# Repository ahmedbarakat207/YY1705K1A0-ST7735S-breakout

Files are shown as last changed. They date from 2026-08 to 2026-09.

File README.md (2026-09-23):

# YY1705K1A0 ST7735S 1-Layer Breakout & Driver Library






An open-source, **1-layer single-sided PCB breakout board** and **high-performance C++ driver** for the **YY1705K1A0** 1.8-inch TFT LCD SPI display (ST7735S controller, 128×160 RGB).

---

## Features

- **100% Single-Sided (1-Layer F.Cu)**: Designed specifically for home etching (toner transfer / photoresist). Zero jumpers or bottom vias required.
- **Through-Hole Passives (no SMD soldering)**: R1, R2, R3, C1, C2 are all standard through-hole parts — solder them with any basic iron. The only SMD part is the J2 FPC ZIF connector (required by the display flex cable).
- **Zero DRC Violations**: Optimized trace widths (0.35 mm signals, 0.60 mm power/GND) with 0.30 mm minimum clearances.
- **Clean Silkscreen**: Professional component labeling with open routing corridors.
- **Header-Only C++ Driver (`YY1705K1A0.h`)**:
  - Hardware SPI (fast DMA-capable) and Software bit-bang SPI constructors.
  - Complete 23-color RGB565 palette + `TFT_COLOR(r,g,b)` macro.
  - Fast graphic primitives (pixels, lines, rects, rounded rects, circles, triangles).
  - Built-in 5×7 ASCII font with scaling and Arduino `Print` interface (`print`/`println`).
  - Pre-built UI widgets (`drawProgressBar`).
  - Native support for display sleep, vertical scrolling, rotation (0°–270°), and partial mode.

---

## Hardware Overview

| Parameter | Specification |
|---|---|
| **Display Model** | YY1705K1A0 (1.8" TFT, 128×160) |
| **Driver IC** | Sitronix ST7735S |
| **Board Dimensions** | 34.0 mm × 53.0 mm |
| **Layers** | 1-Layer (Top Copper `F.Cu` Only) |
| **Interface** | 4-Wire SPI (3.3V Logic) |
| **Connectors** | `J1`: 7-Pin 2.54mm Header, `J2`: 12-Pin 0.5mm FPC |

---

## Pinout & Wiring

> **IMPORTANT**: This board and display operate strictly on **3.3V logic**. When interfacing with 5V microcontrollers (e.g. Arduino Uno / Mega), use a logic level shifter.

| J1 Pin | Label | Function | FPC Pin (J2) | MCU Connection (e.g., ESP32 / Arduino) |
|:---:|:---:|---|:---:|---|
| **1** | `+3V3` | +3.3V Power Supply | Pin 10 (`VDD`) | 3.3V Power Out |
| **2** | `GND` | Ground | Pins 2, 4, 11 | GND |
| **3** | `RST` | Reset (Active LOW) | Pin 5 (`RES`) | GPIO (e.g., D8) |
| **4** | `DC` | Data / Command Select | Pin 6 (`A0`) | GPIO (e.g., D9) |
| **5** | `MOSI` | SPI Data (SDA) | Pin 7 (`SDA`) | SPI MOSI (e.g., D11 / GPIO 23) |
| **6** | `SCK` | SPI Clock (SCL) | Pin 8 (`SCL`) | SPI SCK (e.g., D13 / GPIO 18) |
| **7** | `CS` | Chip Select (Active LOW) | Pin 9 (`CS`) | GPIO (e.g., D10 / GPIO 5) |

---

## Bill of Materials (BOM)

| Designator | Description | Package / Footprint | Quantity |
|---|---|---|:---:|
| **J1** | 7-Pin 2.54mm Header Male/Female | 1×07 Pin Header (0.1") THT | 1 |
| **J2** | 12-Pin 0.5mm Pitch Bottom-Contact FPC Connector | SMD 12-Pin 0.5mm **(only SMD part)** | 1 |
| **R1** | 22 Ω Backlight Current Limiter | Axial 1/4W THT, 7.62mm pitch (lying flat) | 1 |
| **R2, R3** | 10 kΩ Pull-up Resistors (`RESET`, `CS`) | Axial 1/4W THT, 5.08mm pitch (vertical mount) | 2 |
| **C1** | 10 µF 10V Ceramic/Electrolytic (Bulk Decoupling) | Disc/Radial THT, 5mm pitch | 1 |
| **C2** | 100 nF (0.1 µF) Ceramic Disc (HF Bypass) | Disc THT, 5mm pitch | 1 |

---

## Quick Start (Arduino / PlatformIO)

### Installation

1. Copy `YY1705K1A0.h` into your Arduino sketch folder or PlatformIO project `include/` directory.
2. In your sketch:

```cpp
#include <SPI.h>
#include "YY1705K1A0.h"

// Define pins
#define TFT_CS    10
#define TFT_DC    9
#define TFT_RST   8

// Hardware SPI instance (Fastest)
YY1705K1A0 tft(TFT_CS, TFT_DC, TFT_RST);

void setup() {
    // Initialize display with standard black-tab profile
    tft.begin(INITR_BLACKTAB);
    tft.fillScreen(TFT_BLACK);

    // Print text
    tft.setTextColor(TFT_WHITE, TFT_BLACK);
    tft.drawString(10, 20, "Hello World!", TFT_YELLOW, TFT_BLACK, 2);

    // Draw UI shapes
    tft.drawRoundRect(10, 60, 108, 30, 4, TFT_CYAN);
    tft.drawProgressBar(10, 100, 108, 14, 75, TFT_GREEN, TFT_DARKGREY, TFT_WHITE);
}

void loop() {
}
```

---

## DIY PCB Fabrication (Toner Transfer)

Print-ready vector PDF files scaled at 1:1 for DIY etching:

- **[YY1705K1A0_breakout_scaled_landscape.pdf](YY1705K1A0_breakout_scaled_landscape.pdf)**: 2 scaled boards per A4 page.
- **[YY1705K1A0_breakout_scaled_landscape_mirrored.pdf](YY1705K1A0_breakout_scaled_landscape_mirrored.pdf)**: Mirrored for direct iron-on toner transfer.

> **Printing Note**: Print with **Scale: 100% / Actual Size** enabled in your PDF viewer.

---

## Repository Structure

```
├── README.md                                          # Project documentation
├── LICENSE                                            # MIT Open-Source License
├── library.properties                                 # Arduino Library descriptor
├── library.json                                       # PlatformIO Library descriptor
├── YY1705K1A0.h                                       # Display driver header library
├── YY1705K1A0_breakout.kicad_pro                      # KiCad project file
├── YY1705K1A0_breakout.kicad_sch                      # KiCad schematic
├── YY1705K1A0_breakout.kicad_pcb                      # KiCad 1-layer PCB layout
├── BOM.csv                                            # Bill of Materials
├── display_connector_pinout.csv                       # FPC 12-pin reference sheet
├── WIRING_GUIDE.md                                    # Detailed wiring instructions
├── YY1705K1A0_breakout_scaled_landscape.pdf           # Printable A4 etching mask
├── YY1705K1A0_breakout_scaled_landscape_mirrored.pdf  # Mirrored etching mask
└── examples/
    └── GraphicTest/
        └── GraphicTest.ino                            # Complete demo sketch
```

---

## License

This project is open-source hardware and software licensed under the [MIT License](LICENSE).

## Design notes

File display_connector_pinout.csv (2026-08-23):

Pin | Signal | Function | Connection | Notes
1 | LEDA | Backlight anode | +3.3V rail | Through 22 ohm 1/4W SMD resistor in series
2 | LEDK | Backlight cathode | GND plane | Direct connection
3 | VDD | Logic power | +3.3V rail | Place 10uF and 0.1uF decoupling caps to GND at this pin
4 | VDDIO | IO logic power | Pin 3 (+3.3V) | Tie directly to VDD
5 | GND | Ground | GND plane | Direct connection
6 | RESET | Reset signal | GPIO4 | Optional 10k ohm pull-up to 3.3V
7 | DC / A0 | Data/command select | GPIO2 | Direct connection
8 | SDA / MOSI | SPI data | GPIO23 | Direct connection
9 | SCL / SCK | SPI clock | GPIO18 | Direct connection
10 | CS | Chip select | GPIO5 | Optional 10k ohm pull-up to 3.3V
11 | Shield / core GND | Shield ground | GND plane | Direct connection
12 | NC | Not connected | None | Leave pad isolated - do not route

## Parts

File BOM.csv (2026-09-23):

Reference | Value | Footprint | Qty | Description | Manufacturer | MPN | Mouser / LCSC PN | Notes
J2 | FPC_ZIF_12_0.5mm | Local:FPC_12_0.5mm | 1 | 12-pin 0.5mm pitch ZIF FPC connector top-contact (SMD — only SMD part on board) | Molex | 54548-1271 | 538-54548-1271 | Must match display flex cable pitch — verify with calipers.
J1 | ESP32_HDR_7 | PinHeader_1x07_P2.54mm | 1 | 1×7 2.54mm break-away male pin header (through-hole) | Any |  |  | Mating: 2.54mm female Dupont socket
R1 | 22R | Resistor_THT:R_Axial_DIN0207_L6.3mm_D2.5mm_P7.62mm_Horizontal | 1 | 22 ohm 1/4W axial THT resistor — LEDA backlight current limiter | Yageo | CFR-25JB-52-22R | 71-CFR-25JB-52-22R | Standard 1/4W carbon film or metal film axial (lying flat, 7.62mm lead pitch)
R2 | 10k | Resistor_THT:R_Axial_DIN0207_L6.3mm_D2.5mm_P5.08mm_Vertical | 1 | 10k ohm 1/4W axial THT — RESET pull-up resistor (vertical mount) | Yageo | CFR-25JB-52-10KL | 71-CFR-25JB-52-10KL | Vertical mount, 5.08mm lead pitch — stand one lead straight up
R3 | 10k | Resistor_THT:R_Axial_DIN0207_L6.3mm_D2.5mm_P5.08mm_Vertical | 1 | 10k ohm 1/4W axial THT — CS pull-up resistor (vertical mount) | Yageo | CFR-25JB-52-10KL | 71-CFR-25JB-52-10KL | Vertical mount, 5.08mm lead pitch — stand one lead straight up
C1 | 10uF | Capacitor_THT:C_Disc_D5.0mm_W2.5mm_P5.00mm | 1 | 10µF 10V+ ceramic disc or radial electrolytic capacitor — VDD bulk | Nichicon | UMT1A100MDD
C2 | 100nF | Capacitor_THT:C_Disc_D5.0mm_W2.5mm_P5.00mm | 1 | 100nF 50V+ ceramic disc capacitor (0.1µF) — VDD HF bypass | Kemet | C315C104M5U5TA | 80-C315C104M5U5TA

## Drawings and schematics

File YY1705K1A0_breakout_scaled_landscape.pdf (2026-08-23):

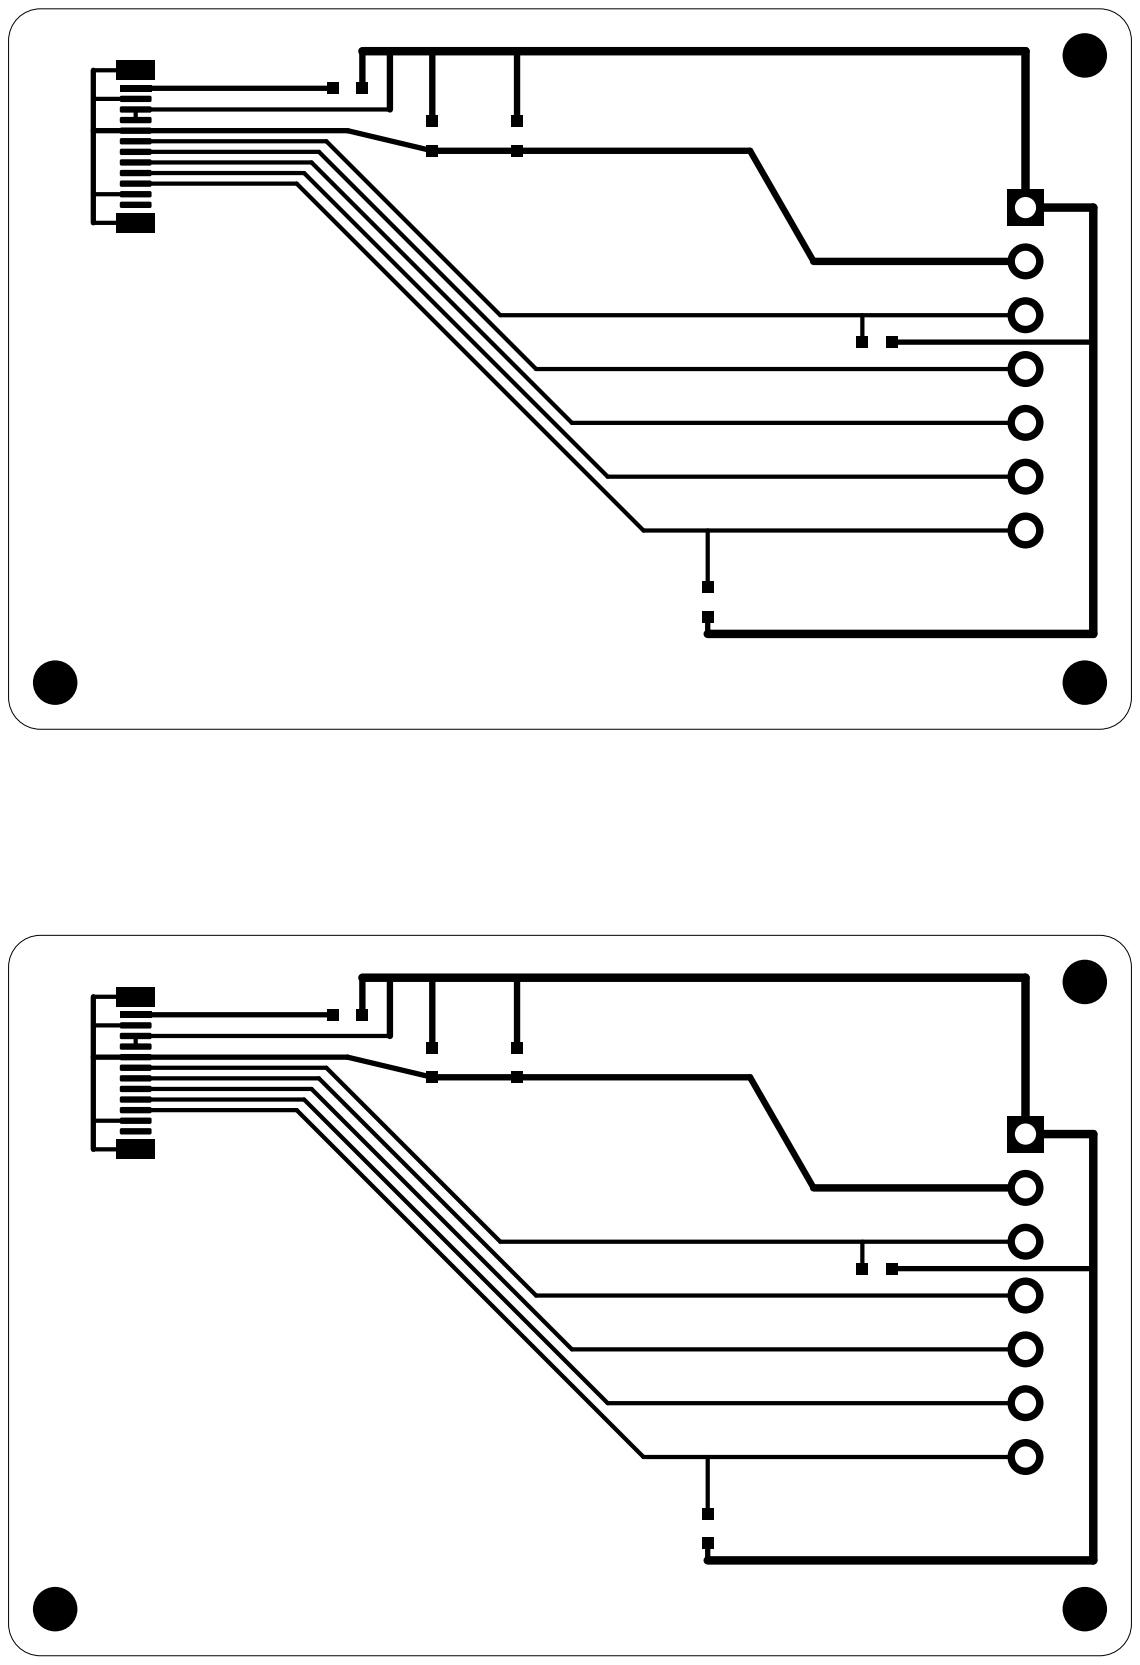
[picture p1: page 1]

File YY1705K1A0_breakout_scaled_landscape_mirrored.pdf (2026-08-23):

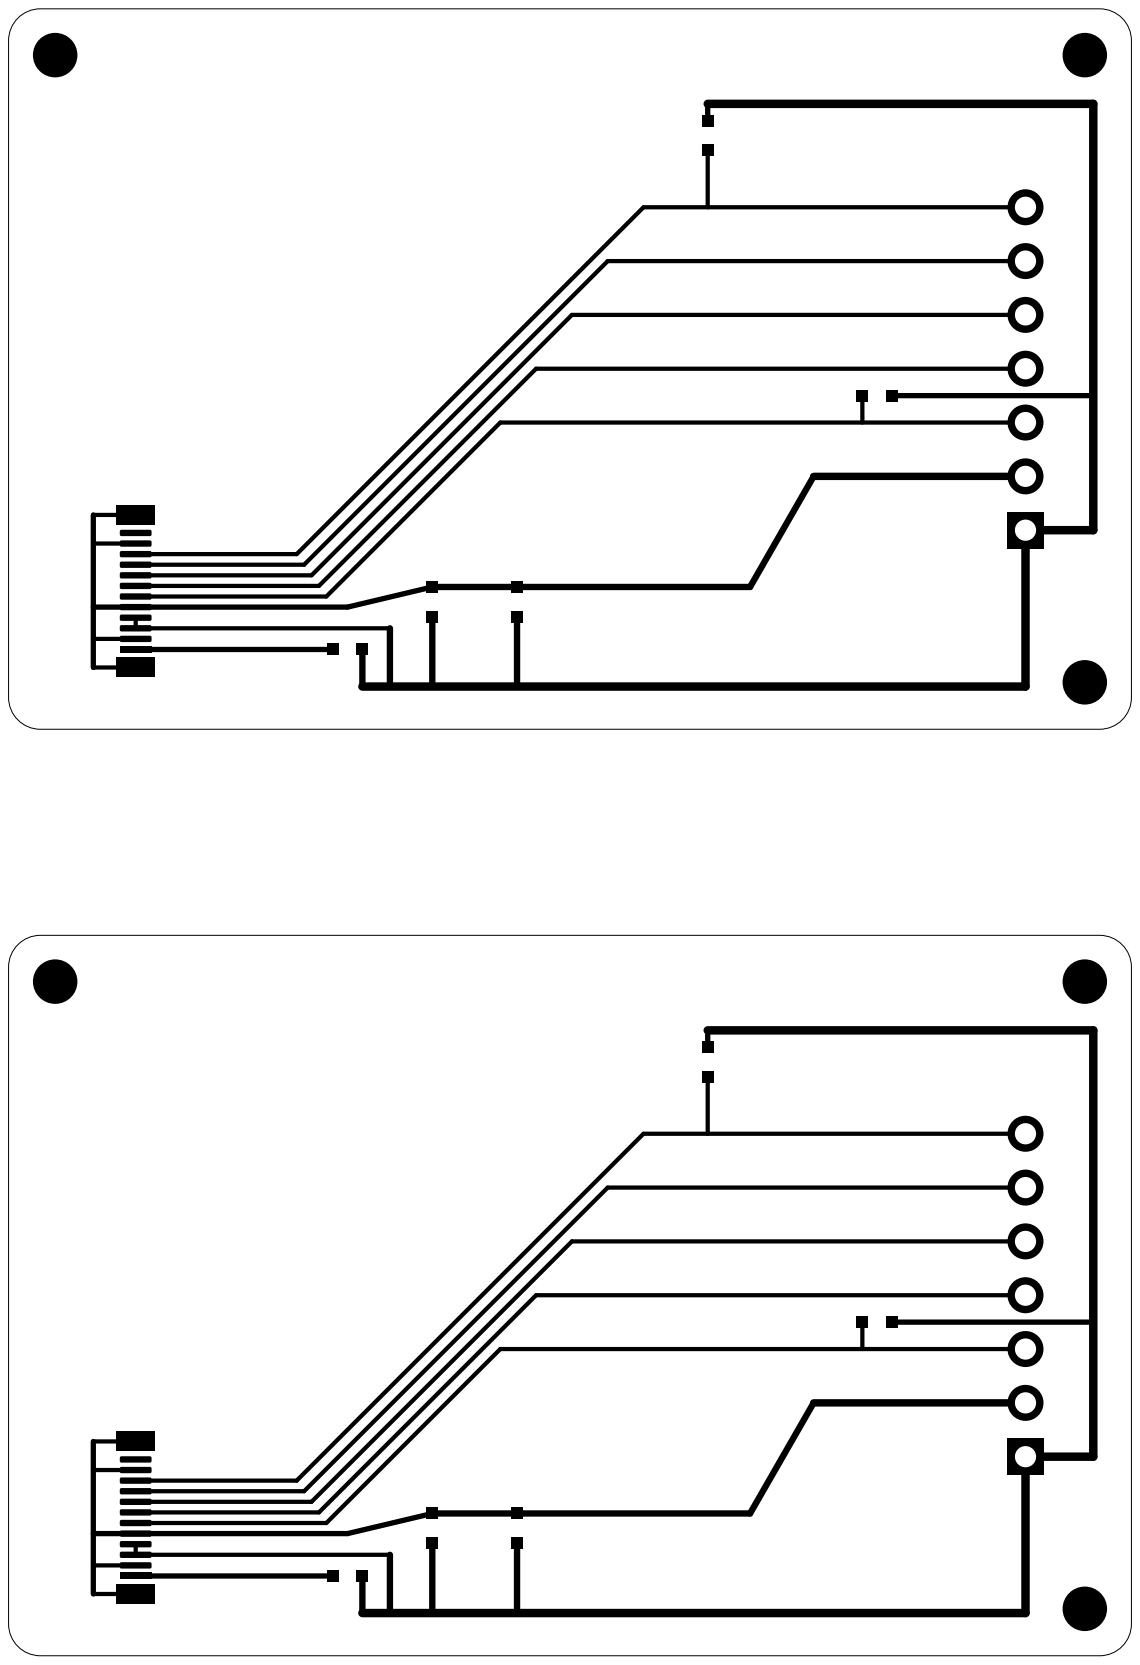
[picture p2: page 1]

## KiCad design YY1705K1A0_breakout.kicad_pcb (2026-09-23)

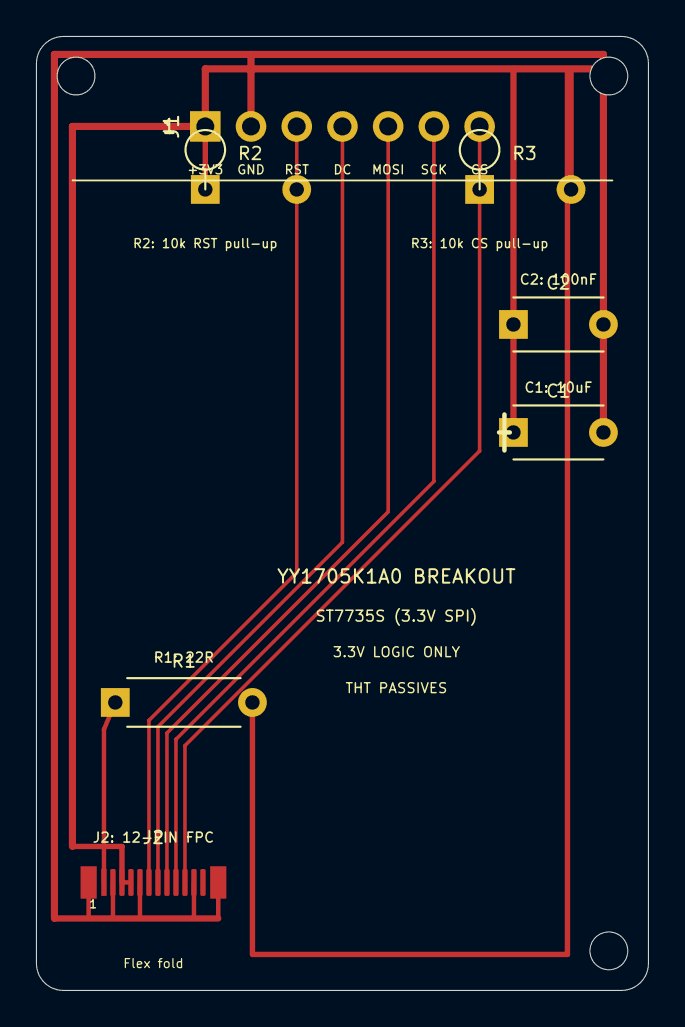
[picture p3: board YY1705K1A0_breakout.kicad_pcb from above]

Board: 2 copper layers, 34.0 x 53.0 mm, 10 parts (0 on the bottom side), 8 nets.

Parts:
C1: 10uF; C_Disc_D5.0mm_W2.5mm_P5.00mm
C2: 100nF; C_Disc_D5.0mm_W2.5mm_P5.00mm
H1, H2, H3: MountingHole_2.1mm
J1: CONN_7PIN; PinHeader_1x07_P2.54mm
J2: FPC_12P_0.5mm; FPC_12_0.5mm
R1: 22R; R_Axial_DIN0207_L6.3mm_D2.5mm_P7.62mm_Horizontal
R2, R3: 10k; R_Axial_DIN0207_L6.3mm_D2.5mm_P5.08mm_Vertical

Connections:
+3V3: C1.1, C2.1, J1.1, J2.3, J2.4, R1.2, R2.1, R3.2
CS: J1.7, J2.10, R3.1
DC_A0: J1.4, J2.7
GND: C1.2, C2.2, J1.2, J2.2, J2.5, J2.11, J2.MP
LEDA_SUPPLY: J2.1, R1.1
RESET: J1.3, J2.6, R2.2
SCL_SCK: J1.6, J2.9
SDA_MOSI: J1.5, J2.8

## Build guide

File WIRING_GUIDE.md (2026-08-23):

# YY1705K1A0 TFT Breakout — Wiring & Software Guide

## Board Overview

| Parameter | Value |
|---|---|
| Display Driver | ST7735S |
| Resolution | 128 × 160 px |
| Interface | 4-wire SPI |
| Logic voltage | **3.3 V only** |
| Board size | 35 × 30 mm |
| Layers | 2 (ENIG finish recommended) |
| FPC connector | 12-pin, 0.5 mm pitch ZIF (top-contact) |

---

## J1 Pin Header — Signal Map

| J1 Pin | Signal | ESP32 GPIO | Arduino Uno | Arduino Nano | Notes |
|---|---|---|---|---|---|
| 1 | **+3V3** | 3V3 | 3.3V | 3.3V | ⚡ **3.3 V only — do NOT connect 5 V** |
| 2 | **GND** | GND | GND | GND | |
| 3 | **RESET** | GPIO4 | D8 | D8 | 10 kΩ pull-up on board |
| 4 | **DC / A0** | GPIO2 | D9 | D9 | Data/Command select |
| 5 | **SDA / MOSI** | GPIO23 | D11 (MOSI) | D11 | Hardware SPI |
| 6 | **SCL / SCK** | GPIO18 | D13 (SCK) | D13 | Hardware SPI |
| 7 | **CS** | GPIO5 | D10 (SS) | D10 | 10 kΩ pull-up on board |

> **Arduino 5V Note:** Arduino Uno/Nano GPIOs are 5 V tolerant outputs but the display requires 3.3 V logic. You must add a **level shifter** (e.g. 74AHCT125) or a **resistor voltage divider** (1 kΩ + 2 kΩ) on MOSI, SCK, CS, DC, RESET lines when using a 5 V Arduino. The ESP32 is natively 3.3 V and needs no level shifting.

---

## On-board Passive Components

| Ref | Value | Function |
|-----|---|---|
| R1 | 22 Ω | LEDA backlight current limit (~50 mA at 3.3 V) |
| R2 | 10 kΩ | RESET line pull-up to 3.3 V |
| R3 | 10 kΩ | CS line pull-up to 3.3 V |
| C1 | 10 µF | VDD bulk decoupling |
| C2 | 100 nF | VDD high-frequency bypass |

---

## Arduino (5 V) — With Level Shifter

```
Arduino Uno               Breakout J1
──────────────────────────────────────
3.3V  ──────────────────► Pin 1 (+3V3)
GND   ──────────────────► Pin 2 (GND)
D8    ─── [Level shift] ► Pin 3 (RESET)
D9    ─── [Level shift] ► Pin 4 (DC/A0)
D11   ─── [Level shift] ► Pin 5 (MOSI)
D13   ─── [Level shift] ► Pin 6 (SCK)
D10   ─── [Level shift] ► Pin 7 (CS)
```

## ESP32 — Direct Connection (no level shifter needed)

```
ESP32                     Breakout J1
──────────────────────────────────────
3V3   ──────────────────► Pin 1 (+3V3)
GND   ──────────────────► Pin 2 (GND)
GPIO4 ──────────────────► Pin 3 (RESET)
GPIO2 ──────────────────► Pin 4 (DC/A0)
GPIO23──────────────────► Pin 5 (MOSI)
GPIO18──────────────────► Pin 6 (SCK)
GPIO5 ──────────────────► Pin 7 (CS)
```

---

## Software — Arduino / ESP32

Install via Arduino Library Manager: **Adafruit ST7735 and ST7789 Library** + **Adafruit GFX Library**

### ESP32 Example Sketch

```cpp
#include <Adafruit_GFX.h>
#include <Adafruit_ST7735.h>
#include <SPI.h>

// Pin definitions matching J1 header
#define TFT_CS    5   // GPIO5
#define TFT_RST   4   // GPIO4
#define TFT_DC    2   // GPIO2
// MOSI = GPIO23 (hardware SPI)
// SCK  = GPIO18 (hardware SPI)

Adafruit_ST7735 tft = Adafruit_ST7735(TFT_CS, TFT_DC, TFT_RST);

void setup() {
  Serial.begin(115200);
  tft.initR(INITR_BLACKTAB);   // Init ST7735S with black tab
  tft.setRotation(1);           // Landscape
  tft.fillScreen(ST77XX_BLACK);
  tft.setCursor(10, 40);
  tft.setTextColor(ST77XX_WHITE);
  tft.setTextSize(2);
  tft.println("Hello TFT!");
}

void loop() {}
```

### Arduino Uno Example Sketch

```cpp
#include <Adafruit_GFX.h>
#include <Adafruit_ST7735.h>
#include <SPI.h>

#define TFT_CS   10
#define TFT_RST   8
#define TFT_DC    9
// MOSI = D11, SCK = D13 (hardware SPI)

Adafruit_ST7735 tft = Adafruit_ST7735(TFT_CS, TFT_DC, TFT_RST);

void setup() {
  tft.initR(INITR_BLACKTAB);
  tft.fillScreen(ST77XX_BLUE);
  tft.setCursor(5, 30);
  tft.setTextColor(ST77XX_WHITE);
  tft.setTextSize(1);
  tft.println("YY1705K1A0 OK");
}

void loop() {}
```

---

## Gerber Export Settings (KiCad)

For JLCPCB / PCBWay fabrication:

| Setting | Value |
|---|---|
| Layers | F.Cu, B.Cu, F.Mask, B.Mask, F.Paste, F.SilkS, B.SilkS, Edge.Cuts |
| Format | Gerber RS-274X |
| Drill files | Excellon, separate file |
| Copper finish | ENIG (recommended for FPC connector pads) |
| Board thickness | 1.6 mm |
| Min track/space | 0.2 / 0.2 mm |
| Min hole | 0.3 mm |

---

## Troubleshooting

| Symptom | Likely cause | Fix |
|---|---|-----|
| White/blank screen | Wrong `initR()` tab colour | Try `INITR_GREENTAB` or `INITR_REDTAB` |
| Garbled/shifted image | Wrong rotation | Call `tft.setRotation(0–3)` |
| No display at all | SPI not reaching display | Check 3.3V power and all SPI lines with oscilloscope |
| Backlight off | R1 open or LEDA not connected | Verify R1 22Ω continuity; LEDA should see ~3.1V |
| Display resets randomly | RESET pull-up missing | R2 10kΩ on board; verify soldering |
| High current draw | LEDA shorted | Verify R1 in series with LEDA; check not bypassed |

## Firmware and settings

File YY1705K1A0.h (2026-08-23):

#pragma once
#ifndef YY1705K1A0_H
#define YY1705K1A0_H

#include <Arduino.h>
#include <SPI.h>

#define TFT_WIDTH           128
#define TFT_HEIGHT          160
#define TFT_SPI_FREQ        32000000UL

#define INITR_GREENTAB      0x00
#define INITR_REDTAB        0x01
#define INITR_BLACKTAB      0x02
#define INITR_GREENTAB2     0x03
#define INITR_MINI160x80    0x04

#define ST7735_NOP          0x00
#define ST7735_SWRESET      0x01
#define ST7735_RDDID        0x04
#define ST7735_RDDST        0x09
#define ST7735_SLPIN        0x10
#define ST7735_SLPOUT       0x11
#define ST7735_PTLON        0x12
#define ST7735_NORON        0x13
#define ST7735_INVOFF       0x20
#define ST7735_INVON        0x21
#define ST7735_GAMSET       0x26
#define ST7735_DISPOFF      0x28
#define ST7735_DISPON       0x29
#define ST7735_CASET        0x2A
#define ST7735_RASET        0x2B
#define ST7735_RAMWR        0x2C
#define ST7735_RAMRD        0x2E
#define ST7735_PTLAR        0x30
#define ST7735_VSCRDEF      0x33
#define ST7735_TEOFF        0x34
#define ST7735_TEON         0x35
#define ST7735_MADCTL       0x36
#define ST7735_VSCRSADD     0x37
#define ST7735_IDMOFF       0x38
#define ST7735_IDMON        0x39
#define ST7735_COLMOD       0x3A
#define ST7735_FRMCTR1      0xB1
#define ST7735_FRMCTR2      0xB2
#define ST7735_FRMCTR3      0xB3
#define ST7735_INVCTR       0xB4
#define ST7735_DISSET5      0xB6
#define ST7735_PWCTR1       0xC0
#define ST7735_PWCTR2       0xC1
#define ST7735_PWCTR3       0xC2
#define ST7735_PWCTR4       0xC3
#define ST7735_PWCTR5       0xC4
#define ST7735_VMCTR1       0xC5
#define ST7735_VMOFCTR      0xC7
#define ST7735_WRID2        0xD1
#define ST7735_WRID3        0xD2
#define ST7735_RDID1        0xDA
#define ST7735_RDID2        0xDB
#define ST7735_RDID3        0xDC
#define ST7735_RDID4        0xDD
#define ST7735_GMCTRP1      0xE0
#define ST7735_GMCTRN1      0xE1
#define ST7735_EXTCTRL      0xF0

#define MADCTL_MY           0x80
#define MADCTL_MX           0x40
#define MADCTL_MV           0x20
#define MADCTL_ML           0x10
#define MADCTL_BGR          0x08
#define MADCTL_MH           0x04

#define TFT_BLACK           0x0000
#define TFT_WHITE           0xFFFF
#define TFT_RED             0xF800
#define TFT_GREEN           0x07E0
#define TFT_BLUE            0x001F
#define TFT_CYAN            0x07FF
#define TFT_MAGENTA         0xF81F
#define TFT_YELLOW          0xFFE0
#define TFT_ORANGE          0xFD20
#define TFT_PINK            0xFC18
#define TFT_PURPLE          0x8010
#define TFT_NAVY            0x000F
#define TFT_DARKGREEN       0x03E0
#define TFT_DARKCYAN        0x03EF
#define TFT_MAROON          0x7800
#define TFT_OLIVE           0x7BE0
#define TFT_DARKGREY        0x7BEF
#define TFT_LIGHTGREY       0xC618
#define TFT_GREENYELLOW     0xB7E0
#define TFT_GOLD            0xFEA0
#define TFT_SILVER          0xC618
#define TFT_SKYBLUE         0x867D
#define TFT_VIOLET          0x915C
#define TFT_TRANSPARENT     0x0120

#define TFT_COLOR(r,g,b) \
    ((uint16_t)(((uint16_t)((r)&0xF8)<<8)|(((g)&0xFC)<<3)|((b)>>3)))

static const uint8_t PROGMEM _font5x7[][5] = {
    {0x00,0x00,0x00,0x00,0x00},{0x00,0x00,0x5F,0x00,0x00},
    {0x00,0x07,0x00,0x07,0x00},{0x14,0x7F,0x14,0x7F,0x14},
    {0x24,0x2A,0x7F,0x2A,0x12},{0x23,0x13,0x08,0x64,0x62},
    {0x36,0x49,0x55,0x22,0x50},{0x00,0x05,0x03,0x00,0x00},
    {0x00,0x1C,0x22,0x41,0x00},{0x00,0x41,0x22,0x1C,0x00},
    {0x08,0x2A,0x1C,0x2A,0x08},{0x08,0x08,0x3E,0x08,0x08},
    {0x00,0x50,0x30,0x00,0x00},{0x08,0x08,0x08,0x08,0x08},
    {0x00,0x60,0x60,0x00,0x00},{0x20,0x10,0x08,0x04,0x02},
    {0x3E,0x51,0x49,0x45,0x3E},{0x00,0x42,0x7F,0x40,0x00},
    {0x42,0x61,0x51,0x49,0x46},{0x21,0x41,0x45,0x4B,0x31},
    {0x18,0x14,0x12,0x7F,0x10},{0x27,0x45,0x45,0x45,0x39},
    {0x3C,0x4A,0x49,0x49,0x30},{0x01,0x71,0x09,0x05,0x03},
    {0x36,0x49,0x49,0x49,0x36},{0x06,0x49,0x49,0x29,0x1E},
    {0x00,0x36,0x36,0x00,0x00},{0x00,0x56,0x36,0x00,0x00},
    {0x00,0x08,0x14,0x22,0x41},{0x14,0x14,0x14,0x14,0x14},
    {0x41,0x22,0x14,0x08,0x00},{0x02,0x01,0x51,0x09,0x06},
    {0x32,0x49,0x79,0x41,0x3E},{0x7E,0x11,0x11,0x11,0x7E},
    {0x7F,0x49,0x49,0x49,0x36},{0x3E,0x41,0x41,0x41,0x22},
    {0x7F,0x41,0x41,0x22,0x1C},{0x7F,0x49,0x49,0x49,0x41},
    {0x7F,0x09,0x09,0x09,0x01},{0x3E,0x41,0x49,0x49,0x7A},
    {0x7F,0x08,0x08,0x08,0x7F},{0x00,0x41,0x7F,0x41,0x00},
    {0x20,0x40,0x41,0x3F,0x01},{0x7F,0x08,0x14,0x22,0x41},
    {0x7F,0x40,0x40,0x40,0x40},{0x7F,0x02,0x04,0x02,0x7F},
    {0x7F,0x04,0x08,0x10,0x7F},{0x3E,0x41,0x41,0x41,0x3E},
    {0x7F,0x09,0x09,0x09,0x06},{0x3E,0x41,0x51,0x21,0x5E},
    {0x7F,0x09,0x19,0x29,0x46},{0x46,0x49,0x49,0x49,0x31},
    {0x01,0x01,0x7F,0x01,0x01},{0x3F,0x40,0x40,0x40,0x3F},
    {0x1F,0x20,0x40,0x20,0x1F},{0x3F,0x40,0x38,0x40,0x3F},
    {0x63,0x14,0x08,0x14,0x63},{0x07,0x08,0x70,0x08,0x07},
    {0x61,0x51,0x49,0x45,0x43},{0x00,0x7F,0x41,0x41,0x00},
    {0x02,0x04,0x08,0x10,0x20},{0x00,0x41,0x41,0x7F,0x00},
    {0x04,0x02,0x01,0x02,0x04},{0x40,0x40,0x40,0x40,0x40},
    {0x00,0x01,0x02,0x04,0x00},{0x20,0x54,0x54,0x54,0x78},
    {0x7F,0x48,0x44,0x44,0x38},{0x38,0x44,0x44,0x44,0x20},
    {0x38,0x44,0x44,0x48,0x7F},{0x38,0x54,0x54,0x54,0x18},
    {0x08,0x7E,0x09,0x01,0x02},{0x0C,0x52,0x52,0x52,0x3E},
    {0x7F,0x08,0x04,0x04,0x78},{0x00,0x44,0x7D,0x40,0x00},
    {0x20,0x40,0x44,0x3D,0x00},{0x7F,0x10,0x28,0x44,0x00},
    {0x00,0x41,0x7F,0x40,0x00},{0x7C,0x04,0x18,0x04,0x78},
    {0x7C,0x08,0x04,0x04,0x78},{0x38,0x44,0x44,0x44,0x38},
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
};
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

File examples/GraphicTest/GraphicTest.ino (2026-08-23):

#include <SPI.h>
#include "YY1705K1A0.h"

// Pin definitions (change according to your microcontroller wiring)
#define TFT_CS    10
#define TFT_DC    9
#define TFT_RST   8

// Instantiate driver with Hardware SPI
YY1705K1A0 tft(TFT_CS, TFT_DC, TFT_RST);

void setup() {
    Serial.begin(115200);

    // Initialize display with standard black tab profile (YY1705K1A0)
    tft.begin(INITR_BLACKTAB);
    tft.setRotation(0);
    tft.fillScreen(TFT_BLACK);

    // Title text
    tft.setTextColor(TFT_YELLOW, TFT_BLACK);
    tft.setTextSize(1);
    tft.drawString(10, 10, "YY1705K1A0 DEMO", TFT_YELLOW, TFT_BLACK, 1);

    // Drawing geometric shapes
    tft.drawRect(10, 25, 108, 40, TFT_CYAN);
    tft.fillRoundRect(15, 30, 98, 30, 4, TFT_NAVY);
    tft.drawString(25, 40, "ST7735S 1.8\"", TFT_WHITE, TFT_NAVY, 1);

    // Circles & triangles
    tft.drawCircle(30, 90, 15, TFT_RED);
    tft.fillCircle(30, 90, 10, TFT_GREEN);
    tft.fillTriangle(70, 75, 55, 105, 85, 105, TFT_MAGENTA);
    tft.drawTriangle(105, 75, 90, 105, 120, 105, TFT_GOLD);

    // Progress bar
    for (int p = 0; p <= 100; p += 5) {
        tft.drawProgressBar(10, 130, 108, 14, p, TFT_GREEN, TFT_DARKGREY, TFT_WHITE);
        delay(30);
    }
}

void loop() {
    // Rotation test cycle
    for (uint8_t r = 0; r < 4; r++) {
        tft.setRotation(r);
        tft.fillScreen(TFT_BLACK);
        tft.drawString(10, 10, "Rotation Test", TFT_GREENYELLOW, TFT_BLACK, 1);
        tft.setCursor(10, 30);
        tft.setTextColor(TFT_WHITE, TFT_BLACK);
        tft.print("Mode: ");
        tft.print(r);
        delay(1000);
    }
}
